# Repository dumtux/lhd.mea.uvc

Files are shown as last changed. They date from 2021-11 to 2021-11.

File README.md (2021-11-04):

# UVC Sterilizer

## Downloading firmware to the board.

Install [MSPDebug](https://github.com/dlbeer/mspdebug).

```sh
sudo apt install mspdebug
```

Plug the board to the computer via USB cable.
Download the firmware to the board.

```sh
mspdebug rom-bsl -d /dev/ttyUSB0 "prog firmware/meauvc/meauvc.ino.MSP-EXP430G2ET2553LP.hex"
```

After finished, unplug the USB cable, and replug it in a few seconds. Then the MCU will be reset and start with the newly downloaded firmware.

For Windows, use the prebuilt binary of [MSPTool](https://github.com/upsidedownlabs/msptool).

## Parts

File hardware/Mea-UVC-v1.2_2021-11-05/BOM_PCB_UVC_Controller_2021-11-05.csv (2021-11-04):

ID | Name | Designator | Footprint | Quantity | Manufacturer Part | Manufacturer | Supplier | Supplier Part | Price
1 | F.35.00041 | UV1,UV2,UV3,UV4,UV5,UV6 | LED-SMD_5P-L3.5-W3.5_UVC-UVA | 6 | F.35.00041 | TUOZHAN | LCSC | C909692 | 0.644
2 | 22uF | C9,C10,C1,C2,C3,C4,C6 | C0805 | 7 | CL21A226MAQNNNE | SAMSUNG | LCSC | C45783 | 0.03
3 | White | LED5,LED6,LED4,LED1,LED2,LED3 | LED0805-FD | 6 | whiteLEDSMD | KENTO | LCSC | C34499
4 | 330 | R9,R10,R5,R15,R16,R17 | R0805 | 6 | 0805W8F3300T5E | UniOhm | LCSC | C17630 | 0.002
5 | 100nF | C19,C31 | C0805 | 2 | CC0805KRX7R9BB104 | YAGEO | LCSC | C49678 | 0.005
6 | USBLC6-4SC6 | D4 | SOT-23-6_L2.9-W1.6-P0.95-LS2.8-BR | 1 | USBLC6-4SC6 | STMicroelectronics | LCSC | C111212 | 0.181
7 | CH340B | U5 | SOIC-16_L9.9-W3.9-P1.27-LS6.0-BL | 1 | CH340B | WCH | LCSC | C81010 | 1.19
8 | B5819W | D1,D2 | SOD-123_L2.8-W1.8-LS3.7-RD | 2 | B5819W | CJ | LCSC | C8598 | 0.044
9 | 2N7002,215 | Q1 | SOT-23_L2.9-W1.3-P1.90-LS2.4-BR | 1 | 2N7002,215 | Nexperia | LCSC | C65189 | 0.068
10 | XC6206P332MR | U3 | SOT-23-3_L2.9-W1.6-P1.90-LS2.8-BR | 1 | XC6206P332MR | TOREX | LCSC | C5446 | 0.108
11 | TP4054 | U4 | SOT-23-5_L3.0-W1.7-P0.95-LS2.8-BR | 1 | TP4054 | TOPPOWER | LCSC | C32574 | 0.121
12 | 10K | R20,R4,R12 | R0805 | 3 | 0805W8F1002T5E | UniOhm | LCSC | C17414 | 0.002
13 | 1M | R18,R19 | R0805 | 2 | 0805W8F1004T5E | UniOhm | LCSC | C17514 | 0.002
14 | 1nF | C5,C7,C8 | C0805 | 3 | CL21B102KBCNNNC | SAMSUNG | LCSC | C46653 | 0.007
15 | SD0805S020S1R0 | D3 | D0805-RD | 1 | SD0805S020S1R0 | AVX | LCSC | C143773 | 0.156
16 | 33 | R2,R3 | R0805 | 2 | 0805W8J0330T5E | UniOhm | LCSC | C25307 | 0.002
17 | 120K | R11 | R0805 | 1 | 0805W8F1203T5E | UniOhm | LCSC | C17436 | 0.003
18 | 51K | R13,R14 | R0805 | 2 | 0805W8F5102T5E | UniOhm | LCSC | C17737 | 0.002
19 | 10uH | L1 | IND-SMD_L3.0-W3.0 | 1 | LVS303012H-100M-N | Chilisin Elec | LCSC | C280522 | 0.053
20 | 100K | R1,R8 | R0805 | 2 | 0805W8F1003T5E | UniOhm | LCSC | C17407 | 0.003
21 | WD3133E-5/TR | U2 | TSOT-23-5_L2.9-W1.6-P0.95-LS2.8-BL | 1 | WD3133E-5/TR | Will Semicon | LCSC | C239785 | 0.14
22 | 2.2uH | L2 | L0805 | 1 | CMI201209U2R2KT | FH | LCSC | C1043 | 0.006
23 | 2.2K | R6 | R0805 | 1 | 0805W8F2201T5E | UniOhm | LCSC | C17520 | 0.002
24 | 680K | R7 | R0805 | 1 | 0805W8F6803T5E | UniOhm | LCSC | C17797 | 0.003
25 | MSP430G2553IPW20 | U1 | TSSOP-20_L6.5-W4.4-P0.65-LS6.4-BL | 1 | MSP430G2553IPW20 | TI | LCSC | C53923 | 2.428
26 | MDS6500AL02LS | CTRL | SW-TH_MDS6500AL02LS | 1 | MDS6500AL02LS | C&K | LCSC | C221825 | 2.179
27 | XH-2PWB | BATT | CONN-SMD_2P-P2.50_XH-2PWB | 1 | XH-2PWB | BOOMELE | LCSC | C64520 | 0.058
28 | AO3415_C181094 | Q2 | SOT-23-3_L2.9-W1.3-P1.90-LS2.4-BR | 1 | AO3415 | Hottech | LCSC | C181094 | 0.081
29 | KSS241GLFS | RST | KEY-SMD_KSS-2G | 1 | KSS241GLFS | C&K | LCSC | C221794 | 0.556
30 | TYPE-C-31-M-12 | USB_C | USB-C_SMD-TYPE-C-31-M-12 | 1 | TYPE-C-31-M-12 | Rectangular Connectors - Contacts | LCSC | C165948 | 0.287

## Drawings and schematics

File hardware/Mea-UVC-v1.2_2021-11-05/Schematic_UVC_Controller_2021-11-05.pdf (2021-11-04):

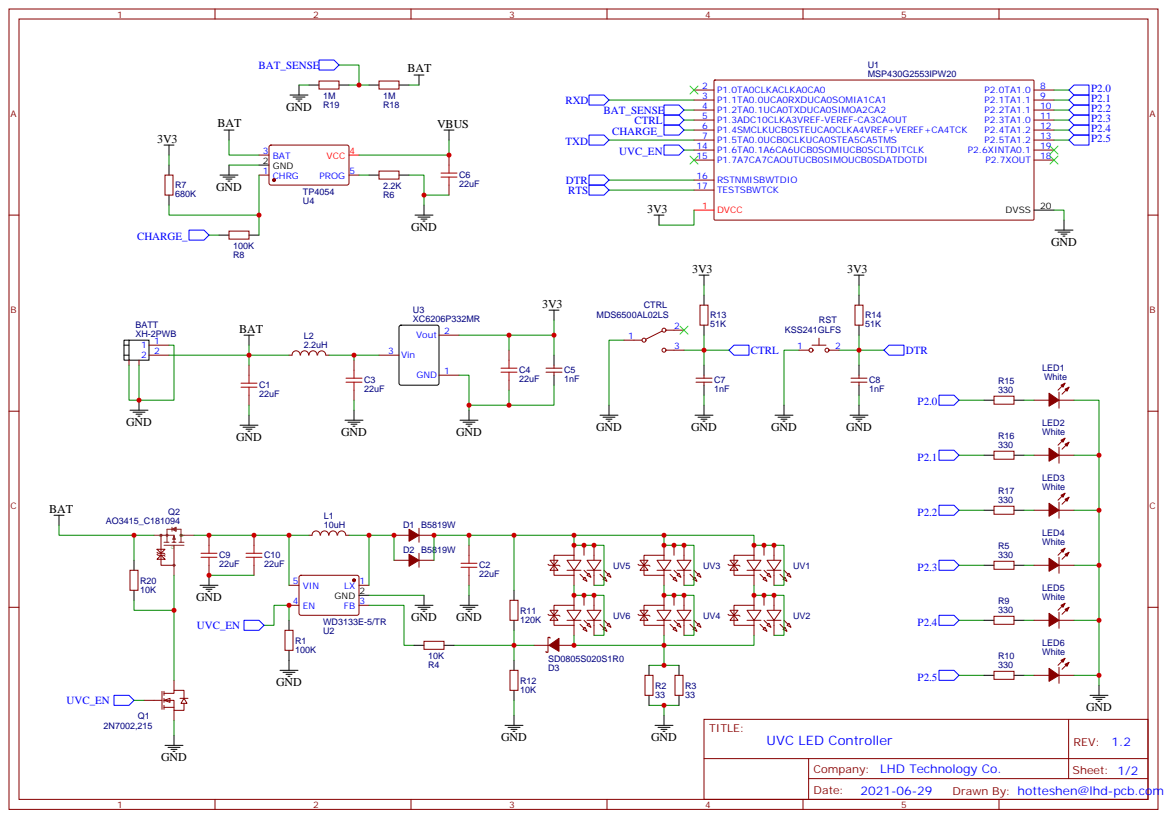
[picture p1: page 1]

Company: LHD Technology Co.

Drawn By: hotteshen@lhd-pcb.com

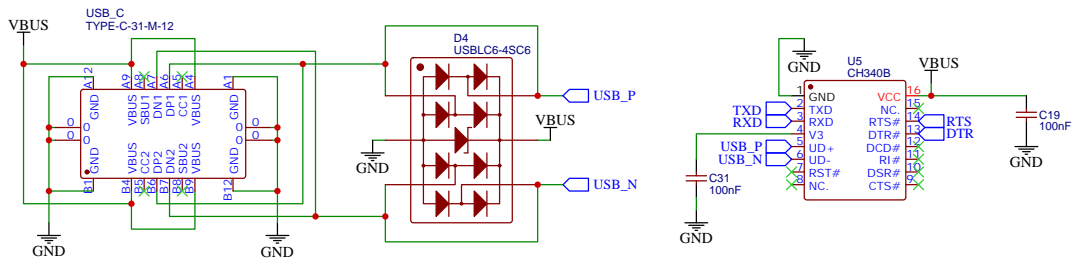
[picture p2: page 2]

DSR# 10 RI# 11 DCD# 12 DTR# 13 RTS# 14 NC. 15 VCC 16

Company: LHD Technology, Co.

Drawn By: hotteshen@lhd-pcb.com

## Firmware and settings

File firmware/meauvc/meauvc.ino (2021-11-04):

#include <Wire.h>

#define LED1 P2_0  // no PWM
#define LED2 P2_1
#define LED3 P2_2
#define LED4 P2_3  // no PWM
#define LED5 P2_4
#define LED6 P2_5

#define CTRL      P1_3
#define CHARGE    P1_4
#define BAT_SENSE P1_2
#define UVC_EN    P1_6

#define DURATION 300000

bool sterilizing = false;
int timer = 0;

void setup() {
  pinMode(LED1, OUTPUT);
  pinMode(LED2, OUTPUT);
  pinMode(LED3, OUTPUT);
  pinMode(LED4, OUTPUT);
  pinMode(LED5, OUTPUT);
  pinMode(LED6, OUTPUT);
  pinMode(UVC_EN, OUTPUT);

  digitalWrite(LED1, LOW);
  digitalWrite(LED2, LOW);
  digitalWrite(LED3, LOW);
  digitalWrite(LED4, LOW);
  digitalWrite(LED5, LOW);
  digitalWrite(LED6, LOW);
  digitalWrite(UVC_EN, LOW);

  pinMode(CTRL, INPUT_PULLUP);
  pinMode(CHARGE, INPUT);
  attachInterrupt(CTRL, ISR_ctrl, CHANGE);


//  pinMode(CHARGE, INPUT);
//  pinMode(BAT_SENSE, INPUT);
//  pinMode(UVC_EN, OUTPUT);
}

void ISR_ctrl() {
    if (digitalRead(CTRL) == HIGH) {
        digitalWrite(LED4, LOW);
        digitalWrite(UVC_EN, LOW);
        sterilizing = false;
        timer = 0;
    } else {
        sterilizing = true;
        timer = 0;
    }
}


void loop() {
    if (timer > DURATION) {
        sterilizing = false;
        timer = 0;
    }

    for (int i = 0; i < 25; i++) {
        if (digitalRead(CHARGE) == LOW) {
            analogWrite(LED2, i*10);
            analogWrite(LED3, i*10);
        } else {
            digitalWrite(LED2, LOW);
            digitalWrite(LED3, LOW);
        }
        if (digitalRead(CTRL) == LOW && sterilizing) {
            analogWrite(LED5, i*10);
            analogWrite(LED6, i*10);
            digitalWrite(LED4, HIGH);
            digitalWrite(UVC_EN, HIGH);
            timer+= 40;
        } else {
            digitalWrite(LED5, LOW);
            digitalWrite(LED6, LOW);
            digitalWrite(LED4, LOW);
            digitalWrite(UVC_EN, LOW);
        }
        delay(40);
    }
    for (int i = 25; i >=0; i--) {
        if (digitalRead(CHARGE) == LOW) {
            analogWrite(LED2, i*10);
            analogWrite(LED3, i*10);
        } else {
            digitalWrite(LED2, LOW);
            digitalWrite(LED3, LOW);
        }
        if (digitalRead(CTRL) == LOW && sterilizing) {
            analogWrite(LED5, i*10);
            analogWrite(LED6, i*10);
            digitalWrite(LED4, HIGH);
            digitalWrite(UVC_EN, HIGH);
            timer += 40;
        } else {
            digitalWrite(LED5, LOW);
            digitalWrite(LED6, LOW);
            digitalWrite(LED4, LOW);
            digitalWrite(UVC_EN, LOW);
        }
        delay(40);
    }
}
